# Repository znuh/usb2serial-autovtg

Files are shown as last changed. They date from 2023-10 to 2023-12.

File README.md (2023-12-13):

# USB2serial-AutoVtg
<br>
USB to serial adapter with automatic target voltage detection, buffered IOs, 1.8V to 5V support and backflow current protection

## Why yet another USB to serial adapter?
This adapter adds several **convenience & protection features** most existing adapters do not have.

I'll use an analogy to explain this: For voltage measurements you can either use a naked analog-to-digital converter (ADC) or a digital multimeter/oscilloscope.
Digital multimeters/oscilloscopes have analog frontends to support different voltage ranges and take a bit of abuse (i.e. overvoltage, etc.) with no permanent damage, while an ADC by itself does not have these features.  
When it comes to USB to serial converters the situation is similar. The converter chip by itself usually doesn't support multiple voltage ranges and can be damaged by overvoltage and overcurrent.

However, an even bigger problem is that adapters can also damage the target system when set to the wrong voltage, or through **backflow current** when connected to an unpowered target. (See [below](#backflow_current) for a detailed explanation.)  
To address these issues, this adapter uses **[buffered IOs](#backflow_current)** with backflow current protection and **[automatic target voltage detection](autovtg)**.

## Adapter Specifications
<table class="table table-striped">
  <tbody class="table-group-divider">
    <tr>
      <td class="td1">IC:</td>
      <td><a href="https://ftdichip.com/products/ft234xd/">FTDI FT234XD</a></td>
    </tr>
    <tr>
      <td class="td1">Signals:</td>
      <td>GND, Rx, Tx, (Vtg - optional Vtarget reference voltage input)</td>
    </tr>
    <tr>
      <td class="td1">IO Voltage:</td>
      <td>1.8V - 5V (automatic detection or via reference pin)</td>
    </tr>
    <tr>
      <td class="td1">Baudrates:</td>
      <td>
		  <ul>
		  <li>4800 Baud - 250kBaud with <a href="#autovtg" class="link-primary">automatic target voltage detection</a></li>
		  <li>300 Baud - 3MBaud with target voltage provided through Vtg pin</li>
		  </ul>
      </td>
    </tr>
    <tr>
      <td class="td1">Buffered IOs:</td>
      <td><a href="https://assets.nexperia.com/documents/data-sheet/74LVC1G17.pdf">74LVC1G17</a> Buffers<br>
      These buffers prevent <a href="#backflow_current" class="link-primary">potentially damaging backflow current</a> when only the target <b>or</b> the USB to Serial Adapter is powered.
      </td>
    </tr>
    <tr>
      <td class="td1">IO Protection:</td>
      <td>120Ω series resistors on Rx/Tx.<br>
      These resistors protect both the USB to Serial Adapter and the target by limiting the short-circuit current 
      when the adapter is connected to the target incorrectly (e.g. adapter Tx connected to target Tx).<br>
      Current limits:
      <ul>
      <li>@1.8V: &lt;15mA</li>
      <li>@3.3V: &lt;28mA</li>
      <li>@5V: &lt;42mA</li>
      </ul>
      </td>
    </tr>
    <tr>
      <td class="td1">Connector:</td>
      <td>USB-C</td>
    </tr>
    <tr>
      <td class="td1">LED:</td>
      <td>Rx/Tx (single LED for both)</td>
    </tr>
</tbody>
</table>

## What is backflow current protection?
The most common USB to Serial Adapters have unbuffered IOs. This means the in- and outputs of the converter IC are
directly connected to the target. When such an adapter is not connected to USB, but to a powered target, current flows
from the output of the target into the input of the converter IC and to Vdd through the 
<a href="https://electronics.stackexchange.com/questions/179450/power-and-ground-clamp-diodes-in-cmos-io-buffer">
clamping diode</a>.  
  
backflow  
  
The same problem occurs when the USB to Serial Adapter is connected to USB and an unpowered target. Current from the
converter output flows into the target input and to Vdd of the target through the input clamping diode.
This penomenon is called
<a href="https://e2e.ti.com/blogs_/b/analogwire/posts/back-powering-why-are-the-lights-on-when-the-power-is-off">
back powering</a>.

Backflow current often exceeds the maximum ratings of the ICs involved. This can permanently damage both the 
(expensive) target and the USB to Serial Adapter. Modern 1.8V devices are more prone to permanent damage through
backflow current because their IOs are significantly less robust than old 5V IOs.<br>
Suitable IO buffers (such as the <a href="https://assets.nexperia.com/documents/data-sheet/74LVC1G17.pdf">74LVC1G17</a>)
prevent this by limiting the backflow current to a few µA.
With these buffers having an unpowered adapter connected to a powered board - and vice versa - no longer poses a risk.

## How does the automatic target voltage detection work?
Connecting a 3.3V USB to Serial Adapter to a 1.8V target (or a 5V adapter to a 3.3V target) can permanently damage
the target, because the excessive voltage can result in a high current through the clamping diode and an overvoltage
on the Vdd supply of the target.

Therefore buffered USB to Serial Adapters usually have a Vtarget (or Vtg/Vref) sense input for the target IO voltage.
The sense input is used to match the IO voltage of the adapter to the target.
This adapter also has such a Vtarget sense input, but in most cases connecting it is optional, because the adapter
can <b>detect the target IO voltage automatically</b> by deriving it from the target Tx signal.

This is done with a <a href="https://www.analog.com/en/technical-articles/ltc6244-high-speed-peak-detector.html">
peak detector circuit</a> based on a common Operational Amplifier (a <a href="https://www.ti.com/product/LMV358A">LMV358A</a>). The automatic detection is designed to work with baud rates ranging from 4800 Baud up to 250kBaud.
For lower or higher baudrates (and for unidirectional use-cases where the target does not have a Tx signal) 
a regular Vtarget sense pin is also available.

The following oscilloscope screenshots show the target TX signal (red) and the recovered IO voltage (blue) at 115.2kBaud and 1.8V. The target is sending 0x00 bytes only - the positive startbits are sufficient to recover the IO voltage.  
115k2_1V8_rx_zeroes_rxon  
Target IO voltage is detected shortly after the first startbit is sent.

115k2_1V8_rx_zeroes_rxoff  
When the target TX signal stays at 0V for a few milliseconds (target is powered off or transmitter shutdown), the recovered IO voltage also drops down to zero.

(115.2kBaud / 5V measurements can be found [here](https://github.com/znuh/usb2serial-autovtg/issues/2#issuecomment-1837257313).)

# License
Designed by Benedikt Heinz &lt;hunz at mailbox.org&gt;

Creative Commons Attribution/Share-Alike, all text above must be included in any redistribution. See license.txt for additional details.

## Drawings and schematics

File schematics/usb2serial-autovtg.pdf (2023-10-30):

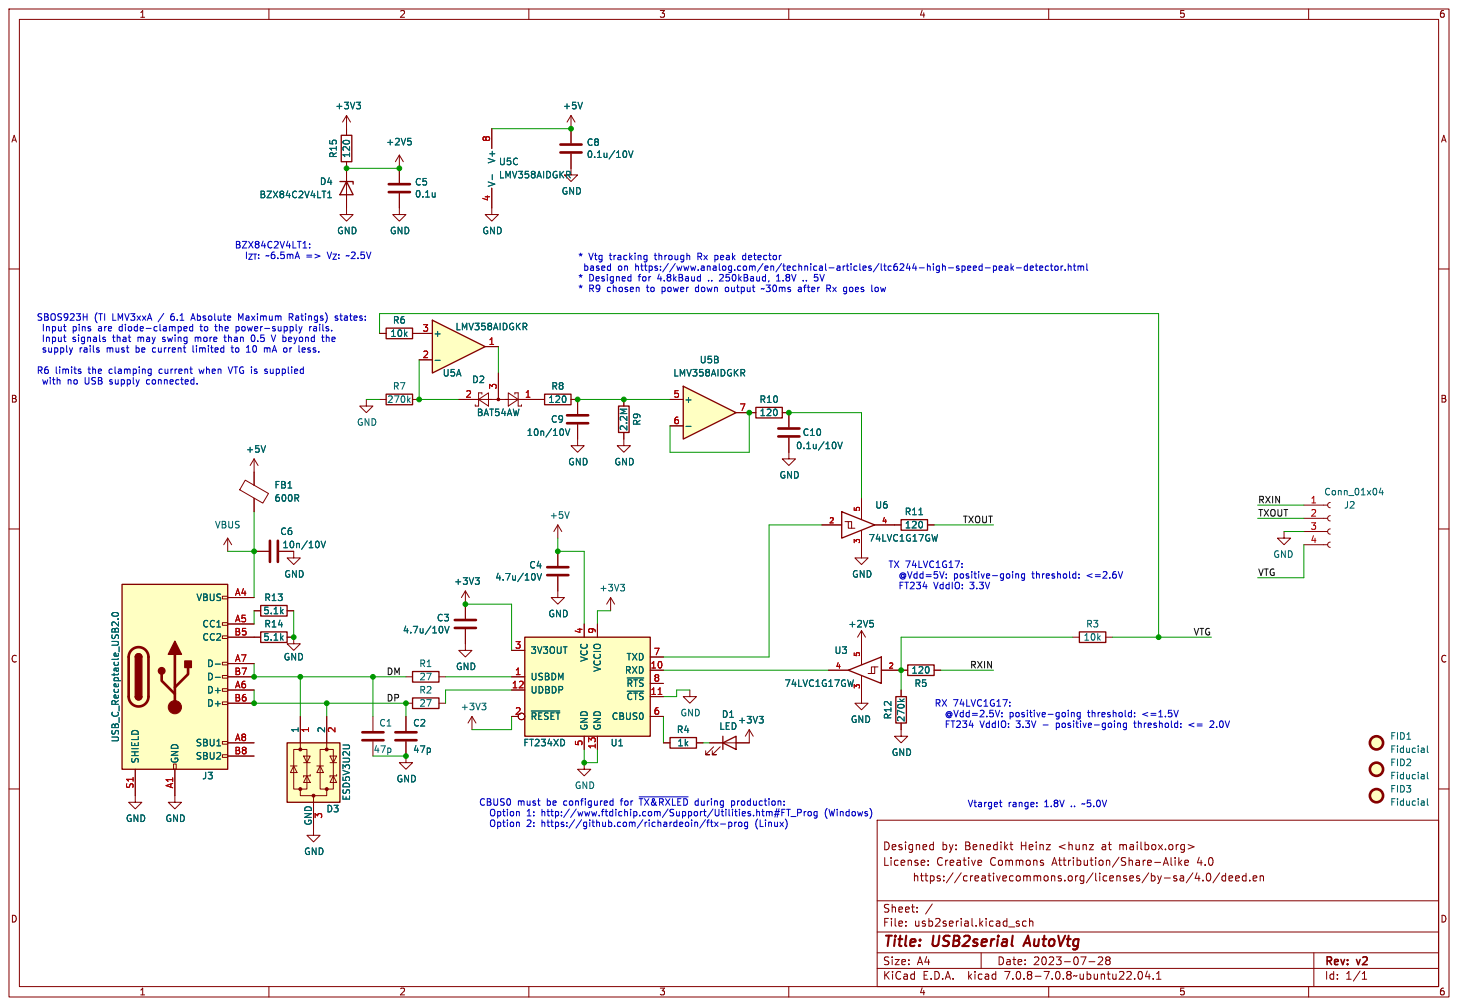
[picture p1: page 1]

* R9 chosen to power down output ~30ms after Rx goes low

Input signals that may swing more than 0.5 V beyond the

File: usb2serial.kicad_sch Sheet: / https://creativecommons.org/licenses/by-sa/4.0/deed.en

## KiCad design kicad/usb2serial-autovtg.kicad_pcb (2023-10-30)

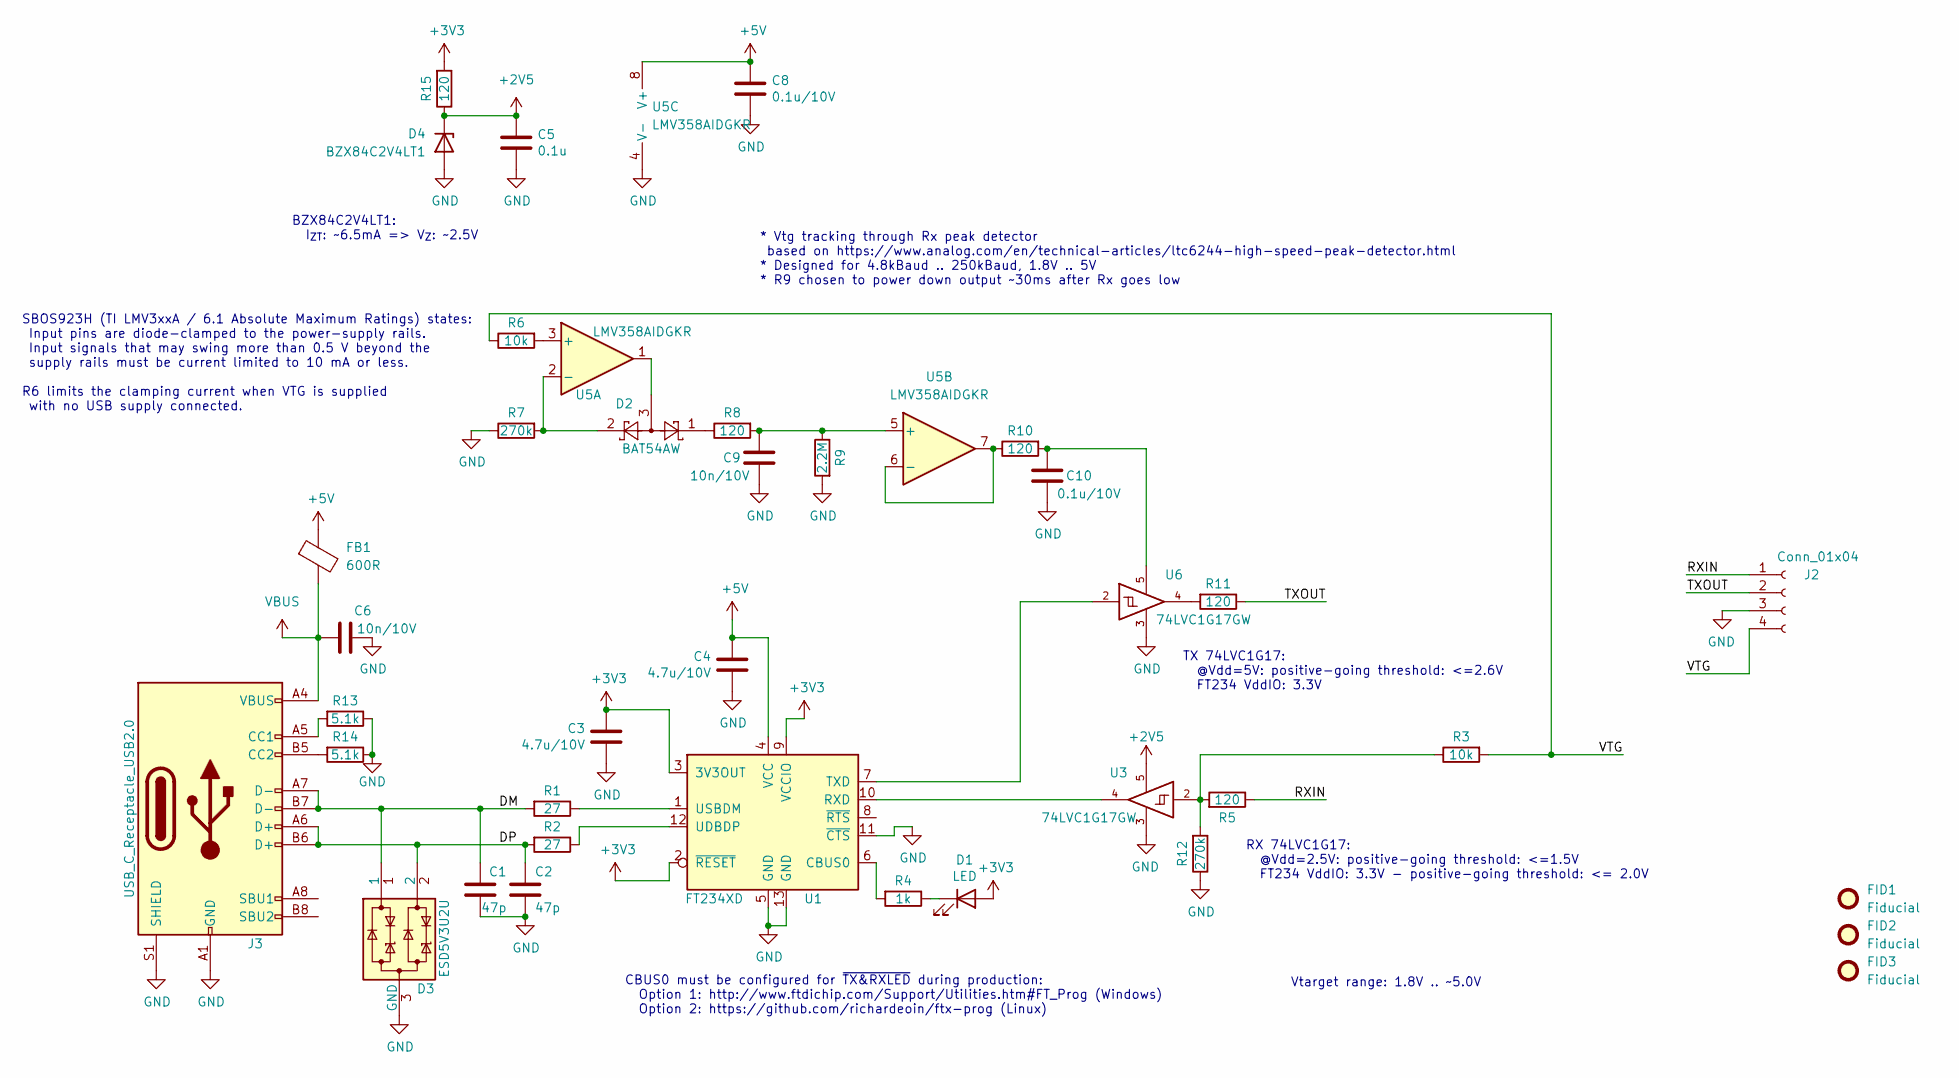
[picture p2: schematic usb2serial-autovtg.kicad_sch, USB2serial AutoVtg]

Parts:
C1, C2: 47p; C_0402_1005Metric
C3, C4: 4.7u/10V; C_0402_1005Metric
C5: 0.1u; C_0402_1005Metric
C6, C9: 10n/10V; C_0402_1005Metric
C8, C10: 0.1u/10V; C_0402_1005Metric
D1: LED; LED_0603_1608Metric
D2: BAT54AW; SOT-323_SC-70
D3: ESD5V3U2U; Infineon_PG-TSFP-3-1
D4: BZX84C2V4LT1; SOT-23
FB1: 600R; L_0603_1608Metric
FID1, FID2, FID3: Fiducial; Fiducial_0.5mm_Mask1mm
J2: Conn_01x04; PinHeader_1x04_P2.54mm_Vertical
J3: USB_C_Receptacle_USB2.0; USB_C_Receptacle_GCT_USB4105-xx-A_16P_TopMnt_Horizontal
R1, R2: 27; R_0402_1005Metric
R3, R6: 10k; R_0402_1005Metric
R4: 1k; R_0402_1005Metric
R5, R8, R10, R11, R15: 120; R_0402_1005Metric
R7, R12: 270k; R_0402_1005Metric
R9: 2.2M; R_0402_1005Metric
R13, R14: 5.1k; R_0402_1005Metric
U1: FT234XD; DFN-12-1EP_3x3mm_P0.45mm_EP1.66x2.38mm
U3, U6: 74LVC1G17GW; TSOP-5_1.65x3.05mm_P0.95mm
U5: LMV358AIDGKR; VSSOP-8_3.0x3.0mm_P0.65mm

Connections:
+2V5: C5.1, D4.3 (K), R15.1, U3.5
+3V3: C3.1, D1.2 (A), R15.2, U1.2 (~RESET), U1.3 (3V3OUT), U1.9 (VCCIO)
+5V: C4.1, C8.1, FB1.1, U1.4 (VCC), U5.8 (V+)
/DM: C1.1, D3.1, J3.A7 (D-), J3.B7 (D-), R1.2
/DP: C2.1, D3.2, J3.A6 (D+), J3.B6 (D+), R2.2
/RXIN: J2.1, R5.1
/TXOUT: J2.2, R11.1
/VTG: J2.4, R3.2, R6.1
GND: C1.2, C2.2, C3.2, C4.2, C5.2, C6.2, C8.2, C9.2, C10.2, D3.3 (GND), D4.1 (A), J2.3, J3.A1 (GND), J3.A12 (GND), J3.B1 (GND), J3.B12 (GND), J3.S1 (SHIELD), R7.1, R9.2, R12.1, R13.1, R14.1, U1.5 (GND), U1.11 (~CTS), U1.13 (GND), U3.3, U5.4 (V-), U6.3
unnamed: C10.1, R10.2, U6.5
unnamed: D1.1 (K), R4.1
unnamed: D2.1, R8.1
unnamed: D2.3, U5.1
unnamed: J3.A5 (CC1), R13.2
unnamed: J3.B5 (CC2), R14.2
unnamed: R11.2, U6.4
unnamed: R3.1, R5.2, R12.2, U3.2
unnamed: R4.2, U1.6 (CBUS0)
unnamed: U1.10 (RXD), U3.4
unnamed: U1.7 (TXD), U6.2
unnamed: R2.1, U1.12 (UDBDP)
unnamed: R1.1, U1.1 (USBDM)
unnamed: R6.2, U5.3 (+)
unnamed: D2.2, R7.2, U5.2 (-)
unnamed: C9.1, R8.2, R9.1, U5.5 (+)
unnamed: R10.1, U5.6 (-), U5.7
VBUS: C6.1, FB1.2, J3.A4 (VBUS), J3.A9 (VBUS), J3.B4 (VBUS), J3.B9 (VBUS)

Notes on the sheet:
CBUS0 must be configured for ~{TX&RXLED} during production: Option 1: http://www.ftdichip.com/Support/Utilities.htm#FT_Prog (Windows) Option 2: https://github.com/richardeoin/ftx-prog (Linux)
TX 74LVC1G17: @Vdd=5V: positive-going threshold: <=2.6V FT234 VddIO: 3.3V
BZX84C2V4LT1: I_{ZT}: ~6.5mA => V_{Z}: ~2.5V
SBOS923H (TI LMV3xxA / 6.1 Absolute Maximum Ratings) states: Input pins are diode-clamped to the power-supply rails. Input signals that may swing more than 0.5 V beyond the supply rails must be current limited to 10 mA or less. R6 limits the clamping current when VTG is supplied with no USB supply 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
* Vtg tracking through Rx peak detector based on https://www.analog.com/en/technical-articles/ltc6244-high-speed-peak-detector.html * Designed for 4.8kBaud .. 250kBaud, 1.8V .. 5V * R9 chosen to power down output ~30ms after Rx goes low
RX 74LVC1G17: @Vdd=2.5V: positive-going threshold: <=1.5V FT234 VddIO: 3.3V - positive-going threshold: <= 2.0V
Vtarget range: 1.8V .. ~5.0V

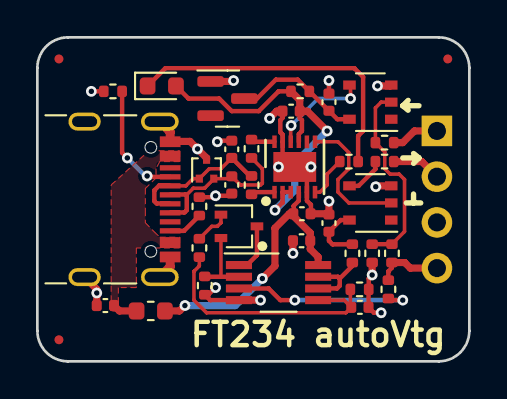
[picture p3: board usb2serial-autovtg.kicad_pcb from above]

Board: 2 copper layers, 24.0 x 18.0 mm, 38 parts (0 on the bottom side), 27 nets.

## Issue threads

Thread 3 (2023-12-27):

A few comments for your OpenLab Augsburg talk

s09bQ5, 2023-12-27:
Hi, just watched your talk and I have a few comments:

 - Those cheap red FT232 boards from AZ-Delivery use a special chip that has a write protected EEPROM. All boards use the same USB serial number, making it difficult to distinguish them if multiple are connected. It also means that it is impossible to use the CBUS pins as GPIOs. I suspect they are cheap clones.
 - RockChip wants 1.5 Mbits/s on the serial console of its SoCs.
 - I sometimes have to deal with RTS/CTS handshaking. I also sometimes have projects with half-duplex RS485/422 where the bus driver has to be turned off after the stop bit (ideally automatically) to be able to receive the answer. But yes, in 95% of all cases RX/TX is enough.
 - In one project the flexibility of the baud rate generator of the FTDI chips came in handy for testing.
 - Being able to receive for each character if it had a parity or framing error (PARMRK) would be nice as well. I remember that some chip marks the whole buffer as bad if there is one error, but I don't remember which chip it was. One would have to check the drivers.
 - Did you have a look at the WCH UARTs? The CH343 can do 6 MBits/s and claims to support an I/O voltage from 1.7V to 5.5V. JLCPCB has them in stock.
 - There are dual supply single gate LVC chips for voltage translation that also cost less than 10 cents. It is allowed to use them with one side unpowered. Search for 74LVC1T45.
 - I was thinking about designing a small board myself before Christmas after we had run out of FT232-AZ boards at work and came to the conclusion that the cheapest and most versatile hardware would use an STM32 clone. But my goal was multiple UARTs + CAN + SPI/JTAG interface.

znuh, 2023-12-28:
> Did you have a look at the WCH UARTs? The CH343 can do 6 MBits/s and claims to support an I/O voltage from 1.7V to 5.5V. JLCPCB has them in stock.
I know these exist but I haven't used them before, so I'm not sure about parts+driver quality. 6MBaud is nice but not super important to have instead of 3M imo. Btw. there's a mistake in the slides - the CP2102N also supports 3MBaud (the slide says 2M).
I'd probably be more inclined to give the CH343 a try if it were also available through digikey, TME, etc. and not just LCSC/JLC.

> There are dual supply single gate LVC chips for voltage translation that also cost less than 10 cents. It is allowed to use them with one side unpowered. Search for 74LVC1T45.
That's a good suggestion. I hadn't thought of these parts b/c initially I started the design without a 2nd supply. Dropping the Zener diode and using the 74LVC1T45 instead makes sense - it also expands the IO voltage down to 1.2V instead of 1.8V.

Regarding PARMRK and handshaking: With this design I want to focus on the most common usage scenarios first. It's always possible to make an "extended" design for more specialized stuff then.

znuh, 2023-12-28:
I've given the 74LVC1T45 a few more thoughts and I see some negative points when using it for RXIN (target -> converter) shifting.
The Nexperia datasheet states:

> In suspend mode when either VCC(A) or VCC(B) are at GND level, both A port and B port are in the high-impedance OFF-state.

So I have to provide VCC(B) to receive data. I see two options for VCC(B):
1. using the recovered Vtarget voltage from the autoVtg circuit
2. using a Zener (or resistor divider) to generate a fixed VCC(B) (e.g. 1.2V - Nexperia datasheet allows V_I up to 6.5V independent of the supply voltage.)

What I don't like about 1) is the dependency on Vtarget. Without the correctly recovered Vtarget the RX path will not work. This means for baudrates <4800 and >250k Vtarget *must* be provided through the pin header because autoVtg can fail.
And if the target transceiver starts sending data immediately after initialization the autoVtg circuit doesn't have enough time to kick in and the first 1-2 bits of the transmitted byte won't be received correctly.

Therefor option 2) would be a better choice. But then again I still need an extra Zener and the main argument for using the 74LVC1T45 is void. (But it would give me 1.2V minimum IO voltage instead of 1.8V.)
So I'm not sure switching to the 74LVC1T45 is worth it 🤔

znuh, 2023-12-28:
Because 1.2V would be nice to have I did some price comparisons (digikey):
- Nexperia 74LVC1G17GW,125 (current design w/ 1.8V min.) @1k: 0,05607 €
- Diodes Inc. 74LVC1T45DW-7 (1.65V min.) @1k: 0,07201 €
- Nexperia 74LVC1T45GW,125 (1.2V min.) @1k: 0,15618 €

As far as I see, both the Diodes Inc. and Nexperia 74LVC1T45 have a SOT363 package, so they can be exchanged. So basically switching to the 74LVC1T45DW-7 makes the whole thing only a tiny bit more expensive and the compatible 74LVC1T45GW,125 can be used for 1.2V (at a slightly higher price). That would justify switching to the 74LVC1T45.

But there's one thing I'm not sure about. Both the Diodes Inc. and Nexperia datasheets more or less state that "I_OFF Controlled by Either VCC Being at 0 V" (quote from Diodes Inc. datasheet). So the I_OFF is only guaranteed as long as VCC(B) is at 0V. (In the Electrical Characteristics tables of both manufacturers I_OFF is only specified with the respective VCC=0V.)
If this is the case Option 2) (VCC(B) powered from Zener) wouldn't be possible because it breaks the I_OFF protection.

Closed 2024-01-08.

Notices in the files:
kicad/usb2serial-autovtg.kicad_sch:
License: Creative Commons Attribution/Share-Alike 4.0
